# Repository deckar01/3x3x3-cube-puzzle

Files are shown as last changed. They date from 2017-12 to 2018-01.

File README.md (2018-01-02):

# 3x3x3 Cube Puzzle

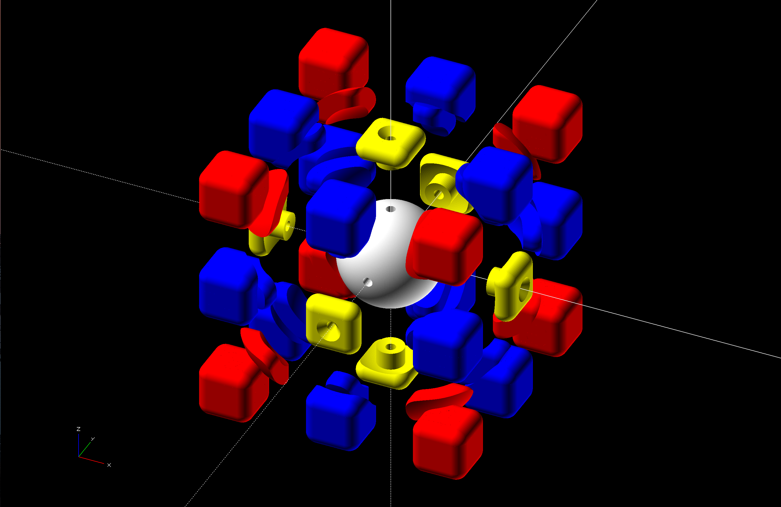
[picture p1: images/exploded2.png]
exploded


## Printing

Use 6 different colors of filament.

 - (1) core piece
 - (6) middle pieces
 - (8) corner pieces
 - (12) edge pieces

## Assembly

 1. Screw five of the center pieces to the core.
 2. Insert 4 corner pieces into the bottom center piece.
 3. Insert 4 edge pieces between each corner piece.
 4. Insert an edge piece between each of the 4 center pieces.
 5. Insert a corner piece above each edge piece.
 6. Insert an edge piece between each corner.
 7. Screw a center piece to the top of the core.
 8. Color sides

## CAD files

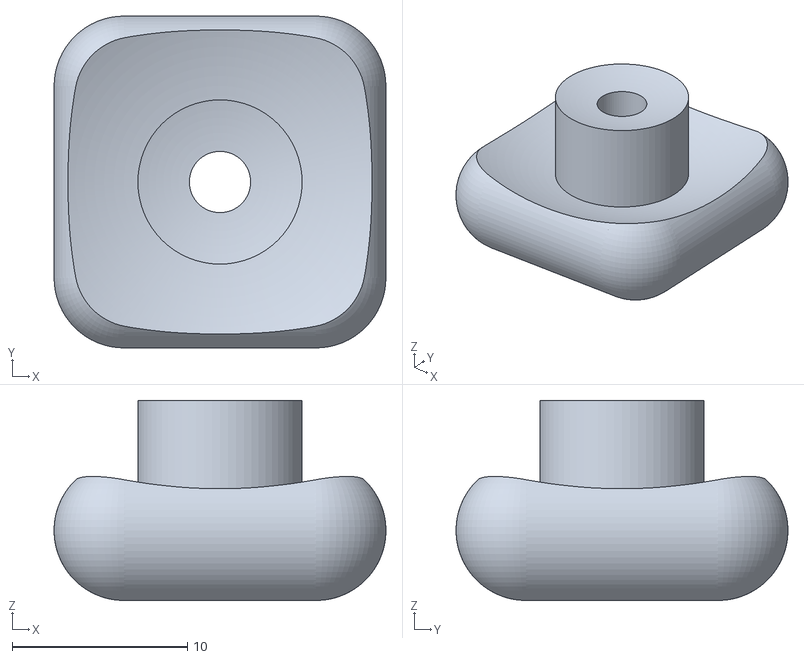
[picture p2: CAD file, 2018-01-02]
objects/center.stl
19.0 x 19.0 x 11.4

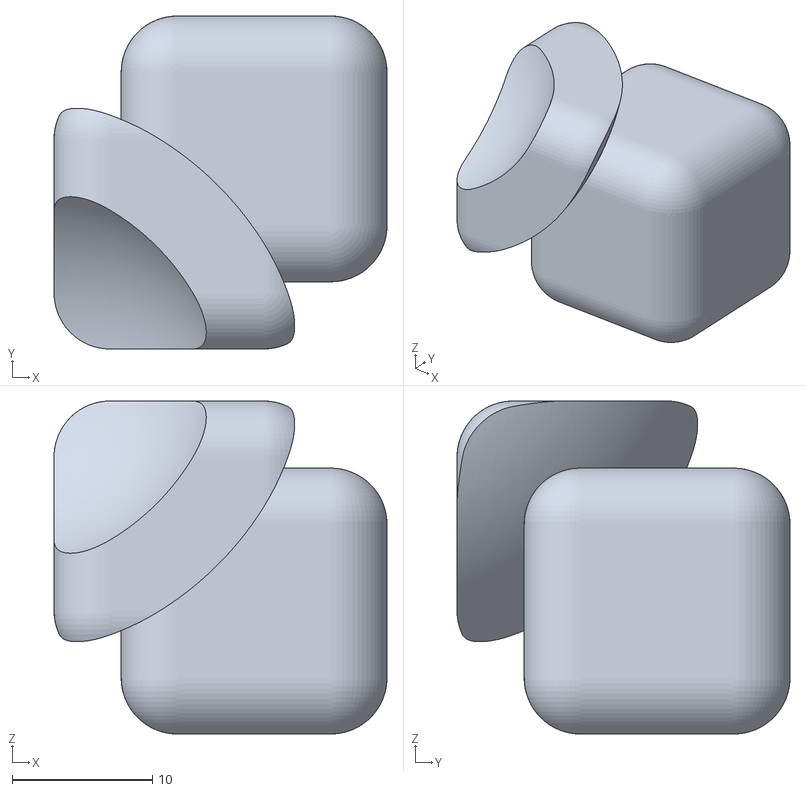
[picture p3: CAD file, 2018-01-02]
objects/corner.stl
23.8 x 23.8 x 23.8

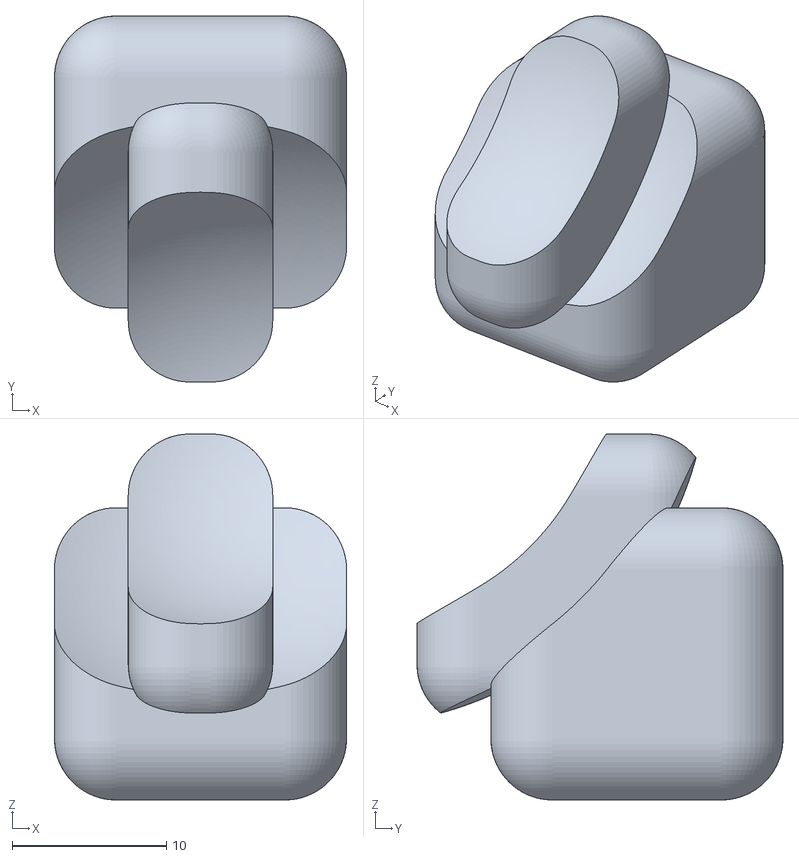
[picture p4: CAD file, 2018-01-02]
objects/edge.stl
19.0 x 23.8 x 23.8

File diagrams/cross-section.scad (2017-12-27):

use <../pieces/corner.scad>;
use <../pieces/edge.scad>;
use <../pieces/center.scad>;
use <../pieces/core.scad>;

translate([0, 0.005, 0.005]) // HACK: Avoid OpenSCAD coloring bug.
color("red")
for(r = [
    [0, 0, 0], [0, 0, 1], [0, 0, 2], [0, 0, 3],
    [1, 0, 0], /*[2, 0, 0],*/ [0, 2, 0], [3, 2, 0],
])
rotate(r*90)
CornerPiece();

translate([0, -0.005, -0.005]) // HACK: Avoid OpenSCAD coloring bug.
color("blue")
for(r = [
    [0, 0, 0], [0, 0, 1], [0, 0, 2], [0, 0, 3],
    [0, 1, 0], [0, 1, 1], /*[0, 1, 2],*/ [0, 1, 3],
    [1, 0, 0], [1, 0, 1], /*[1, 0, 2], [1, 0, 3],*/
])
rotate(r*90)
EdgePiece();

color("yellow")
for(r = [
    [0, 0], /*[0, -1],*/ [0, 1],
    /*[-1, 0],*/ [1, 0], [2, 0],
])
rotate(90*r)
CenterPiece();

color("white")
CorePiece();

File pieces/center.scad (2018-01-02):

use <../utils/rounded-cube.scad>;
include <../settings/default.scad>;
include <../settings/screw.scad>;

module CenterPiece() {
  difference() {
    union() {
      // Cube
      difference() {
        translate([0, 0, -3*piece_width/2 - piece_gap + piece_bevel])
        RoundedCube(
          [piece_width, piece_width, 2*piece_bevel],
          piece_bevel,
          resolution
        );
        
        sphere(r=plate_radius + piece_gap, center=true, $fn=sphere_resolution);
      }

      // Axle
      difference() {
        translate([0, 0, -width/2])
        cylinder(r=skid_width/2, h=width/2, $fn=cylinder_resolution);
        
        sphere(r=plate_radius - plate_thickness, center=true, $fn=sphere_resolution);
      }
    }

    // Countersink
    outer_radius = screw_head_diameter/2 + piece_gap;
    inner_radius = screw_diameter/2 + piece_gap;
    translate([0, 0, -width/2 - screw_head_thickness])
    cylinder(
      r1=2*outer_radius,
      r2=inner_radius,
      h=2*screw_head_thickness,
      $fn=cylinder_resolution
    );

    // Screw hole
    translate([0, 0, -width/2 - 0.1])
    cylinder(r=screw_diameter/2 + piece_gap, h=width/2, $fn=cylinder_resolution);
  }
}

CenterPiece();

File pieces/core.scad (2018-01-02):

include <../settings/default.scad>;
include <../settings/screw.scad>;


module CorePiece() {
  difference() {
    // Ball
    core_radius = plate_radius - plate_thickness - piece_gap;
    sphere(r=core_radius, center=true, $fn=sphere_resolution);

    // Holes
    hole_radius = (screw_diameter - piece_gap)/2;
    hole_angles = [
      [0, 0, 0], [0, 90, 0], [90, 0, 0],
      [180, 90, 0], [0, 180, 0], [-90, 0, 0],
    ];
    for(hole_angle = hole_angles) {
      rotate(hole_angle)
      translate([0, 0, width/2 + screw_diameter])
      cylinder(r=hole_radius, h=width, $fn=cylinder_resolution, center=true);
    }
  }
}

CorePiece();

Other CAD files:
diagrams/exploded.scad
pieces/corner.scad
pieces/edge.scad
settings/default.scad
settings/development.scad
settings/production.scad
settings/screw.scad
utils/rounded-cube.scad

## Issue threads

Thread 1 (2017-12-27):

Add images of assembly steps

deckar01, 2017-12-27:
- [ ] 3D print all the parts
    - [ ] 2 core parts
    - [ ] 6 center parts
    - [ ] 24 edge parts
    - [ ] 24 corner parts
- [ ] Take photos of the loose assembly steps
- [ ] Take apart
- [ ] Take photos of the glued assembly steps
- [ ] Move assembly instructions into a dedicated folder
- [ ] Add images to assembly instructions

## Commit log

2017-12-27 3x3x3 cube puzzle
    [center-piece.stl, center.scad, core.scad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]
2018-01-02 Remove the sliced parts
    [center-piece.stl, center.scad, center.stl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]
2018-01-02 Fix and simplify the corner translation vector
    [corner.scad]
2018-01-02 Clean up indentation and line length
    [center.scad, core.scad, corner.scad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]
2018-01-02 Use a #6-32 x 3/4-in Flat-Head screw
    [screw.scad]
2018-01-02 Increase the outer bevel and decrease the piece gap
    [default.scad, development.scad, production.scad]
